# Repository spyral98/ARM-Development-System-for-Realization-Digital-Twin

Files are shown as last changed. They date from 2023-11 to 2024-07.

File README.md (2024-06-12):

# ARM-Development-System-to-Support-Digital-Twin-of-Stepper-Motor 
This repository consists of the work conducted for the thesis "ARM Development System to Support Digital Twin of Stepper Motor". It contains all the files necessary for the development of a fully functional system built around an STM32 Cortex-M4 microcontroller, as well as the code for a demo application for it. It also contains the code for a data representation application using Matlab.



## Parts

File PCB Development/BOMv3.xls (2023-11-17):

SHOPPING BASKET
This is not an invoice
13-Aug-21 08:47:59
 | Mouser No | Mfr. No | Manufacturer | Customer No | Description | RoHS | Lifecycle | Order Qty. | Price (EUR) | Ext.: (EUR)
1 | 696-SMLLXT0805SIUGUB | SML-LXT0805SIUGUBW | Lumex |  | Standard LEDs - SMD SMT 1.25mm X 2.00mm 632nmR,468nmG,468nmB | RoHS Compliant |  | 1 | 0,635 € | 0,64 €
2 | 815-ABM8-16.0-10-1UT | ABM8-16.000MHZ-10-1-U-T | ABRACON |  | Crystals CRYSTAL 16.0000MHZ 10PF SMD | RoHS Compliant |  | 1 | 0,822 € | 0,82 €
3 | 652-SF-0603HIA350M-2 | SF-0603HIA350M-2 | Bourns |  | Surface Mount Fuses 0603 high-inrush multilayer 3.5A Auto | RoHS Compliant | New Product | 1 | 0,94 € | 0,94 €
4 | 511-STM32L4S9ZIT6 | STM32L4S9ZIT6 | STMicroelectronics |  | ARM Microcontrollers - MCU 16/32-BITS MICROS | RoHS Compliant |  | 1 | 19,63 € | 19,63 €
5 | 652-SF-0603HIA100M-2 | SF-0603HIA100M-2 | Bourns |  | Surface Mount Fuses 1 AMP .24 OHM 32VDC | RoHS Compliant | New Product | 1 | 0,94 € | 0,94 €
6 | 755-RSX101MM-30TFTR | RSX101MM-30TFTR | ROHM Semiconductor |  | Schottky Diodes & Rectifiers 30V VR 1A 0.39V VF PMDU; SOD-123FL | RoHS Compliant By Exemption |  | 2 | 0,457 € | 0,91 €
7 | 748-CM1231-02SO | CM1231-02SO | ON Semiconductor |  | ESD Suppressors / TVS Diodes 2-ch. EP series dual | RoHS Compliant |  | 1 | 0,584 € | 0,58 €
8 | 604-AP2012MGC | AP2012MGC | Kingbright |  | Standard LEDs - SMD GRN WATER CLEAR 0805 | RoHS Compliant |  | 1 | 0,50 € | 0,50 €
9 | 113-DTSZML62KVTR | DTSZML-62K-V-T/R | Diptronics |  | Tactile Switches SMT Type (Pitch4.5mm) | RoHS Compliant |  | 1 | 0,381 € | 0,38 €
10 | 688-SSSS811101 | SSSS811101 | Alps Alpine |  | Slide Switches SPDT HORZ GRND 1.5mm | RoHS Compliant |  | 1 | 1,04 € | 1,04 €
11 | 595-TL1963A-33KTTR | TL1963A-33KTTR | Texas Instruments |  | LDO Voltage Regulators 1.5A Lo-Noise Fast- Trans-Resp LDO Reg | RoHS Compliant |  | 1 | 2,88 € | 2,88 €
12 | 963-FBTH1608HE101-T | FBTH1608HE101-T | Taiyo Yuden |  | Ferrite Beads 0603 100ohm 25% AEC-Q200 | RoHS Compliant |  | 2 | 0,254 € | 0,51 €
13 | 80-C0805C106K3P | C0805C106K3PACTU | KEMET |  | Multilayer Ceramic Capacitors MLCC - SMD/SMT 25V 10uF X5R 0805 10% | RoHS Compliant |  | 2 | 0,288 € | 0,58 €
14 | 80-C0603C104J4RAC | C0603C104J4RAC | KEMET |  | Multilayer Ceramic Capacitors MLCC - SMD/SMT 16V 0.1uF X7R 0603 5% | RoHS Compliant |  | 17 | 0,034 € | 0,58 €
15 | 71-CRCW0603330RJNEB | CRCW0603330RJNEB | Vishay |  | Thick Film Resistors - SMD 1/10watt 330ohms 5% | RoHS Compliant By Exemption |  | 1 | 0,085 € | 0,09 €
16 | 71-RCG060310K0JNEA | RCG060310K0JNEA | Vishay |  | Thick Film Resistors - SMD .1watt 10kohms 5% 0603 200ppm | RoHS Compliant |  | 4 | 0,085 € | 0,34 €
17 | 71-CRCW080522R0JNEAH | CRCW080522R0JNEAHP | Vishay |  | Thick Film Resistors - SMD 1/2watt 22ohms 5% High Power AEC-Q200 | RoHS Compliant By Exemption |  | 30 | 0,171 € | 5,13 €
18 | 71-CRCW060347R0FKEAC | CRCW060347R0FKEAC | Vishay |  | Thick Film Resistors - SMD 1/10Watt 47ohms 1% Commercial Use | RoHS Compliant By Exemption |  | 1 | 0,085 € | 0,09 €
19 | 71-CRCW06032R00FKEAC | CRCW06032R00FKEAC | Vishay |  | Thick Film Resistors - SMD 1/10Watt 2ohms 1% Commercial Use | RoHS Compliant By Exemption |  | 1 | 0,136 € | 0,14 €
20 | 71-CRCW06034K70JNEAC | CRCW06034K70JNEAC | Vishay |  | Thick Film Resistors - SMD 1/10Watt 4.7Kohms 5% Commercial Use | RoHS Compliant By Exemption |  | 10 | 0,027 € | 0,27 €
21 | 80-C0805C105K4R | C0805C105K4RACTU | KEMET |  | Multilayer Ceramic Capacitors MLCC - SMD/SMT 16V 1uF X7R 0805 10% | RoHS Compliant |  | 3 | 0,119 € | 0,36 €
22 | 649-10118194-0001LF | 10118194-0001LF | FCI / Amphenol |  | USB Connectors 5P MICRO USB TYPE B RCPT W/ REAR PEGS | RoHS Compliant |  | 1 | 0,364 € | 0,36 €
23 | 621-DMPH4015SSS-13 | DMPH4015SSS-13 | Diodes Incorporated |  | MOSFET MOSFET BVDSS: 31V-40V |  |  | 1 | 1,13 € | 1,13 €
24 | 538-90136-2106 | 90136-2106 | Molex |  | Headers & Wire Housings 2.54MM CGRIDIII HDR 6P R/A SR SHRD TIN | RoHS Compliant |  | 4 | 1,23 € | 4,92 €
25 | 538-90136-2107 | 90136-2107 | Molex |  | Headers & Wire Housings 2.54MM CGRIDIII HDR 7P R/A SR SHRD TIN | RoHS Compliant |  | 2 | 1,39 € | 2,78 €
26 | 538-90136-2103 | 90136-2103 | Molex |  | Headers & Wire Housings 2.54MM CGRIDIII HDR 3P R/A SR SHRD TIN | RoHS Compliant |  | 1 | 1,48 € | 1,48 €
27 | 538-90136-2104 | 90136-2104 | Molex |  | Headers & Wire Housings 2.54MM CGRIDIII HDR 4P R/A SR SHRD TIN | RoHS Compliant |  | 1 | 1,41 € | 1,41 €
28 | 200-2SNBKG | 2SN-BK-G | Samtec |  | Headers & Wire Housings 2.00 mm Shunt | RoHS Compliant |  | 10 | 0,248 € | 2,48 €
29 | 651-1935187 | 1935187 | Phoenix Contact |  | Fixed Terminal Blocks PT 1.5/4-5.0-H | RoHS Compliant By Exemption |  | 1 | 0,78 € | 0,78 €
30 | 80-C0603C100J3HACTU | C0603C100J3HACTU | KEMET |  | Multilayer Ceramic Capacitors MLCC - SMD/SMT 25V 10pF X8R 0603 5% | RoHS Compliant |  | 2 | 0,085 € | 0,17 €
31 | 80-C0805C475K9P | C0805C475K9PACTU | KEMET |  | Multilayer Ceramic Capacitors MLCC - SMD/SMT 6.3V 4.7uF X5R 0805 10% | RoHS Compliant |  | 2 | 0,186 € | 0,37 €
32 | 80-C0805C225K4P | C0805C225K4PACTU | KEMET |  | Multilayer Ceramic Capacitors MLCC - SMD/SMT 16V 2.2uF X5R 0805 10% | RoHS Compliant |  | 1 | 0,237 € | 0,24 €
33 | 80-C0603C103J5R | C0603C103J5RACTU | KEMET |  | Multilayer Ceramic Capacitors MLCC - SMD/SMT 50V 0.01uF X7R 0603 5% | RoHS Compliant |  | 1 | 0,085 € | 0,09 €
34 | 71-CRCW06031K00JNEAC | CRCW06031K00JNEAC | Vishay |  | Thick Film Resistors - SMD 1/10Watt 1Kohms 5% Commercial Use | RoHS Compliant By Exemption |  | 10 | 0,025 € | 0,25 €
35 | 71-CRCW08050000Z0EAC | CRCW08050000Z0EAC | Vishay |  | Thick Film Resistors - SMD 1/8Watt 0ohms Commercial Use | RoHS Compliant By Exemption |  | 3 | 0,085 € | 0,26 €
36 | 200-SSQ10801FS | SSQ-108-01-F-S | Samtec |  | Headers & Wire Housings Tiger Buy Socket Strip with Square Tails, 0.100 Pitch | RoHS Compliant |  | 2 | 1,37 € | 2,74 €
37 | 200-SSQ10201TS | SSQ-102-01-T-S | Samtec |  | Headers & Wire Housings Tiger Buy Socket Strip with Square Tails, 0.100 Pitch | RoHS Compliant |  | 1 | 0,263 € | 0,26 €
38 | 200-SSQ10101TS | SSQ-101-01-T-S | Samtec |  | Headers & Wire Housings Tiger Buy Socket Strip with Square Tails, 0.100 Pitch | RoHS Compliant |  | 1 | 0,466 € | 0,47 €
39 | 200-SSQ10401LD | SSQ-104-01-L-D | Samtec |  | Headers & Wire Housings Tiger Buy Socket Strip with Square Tails, 0.100 Pitch | RoHS Compliant |  | 1 | 1,49 € | 1,49 €
40 | 200-TSW20207FS | TSW-202-07-F-S | Samtec |  | Headers & Wire Housings Classic PCB Header Strips, 0.100 pitch | RoHS Compliant |  | 2 | 0,373 € | 0,75 €
41 | 200-TMM10303FS | TMM-103-03-F-S | Samtec |  | Headers & Wire Housings Low Profile Tiger Eye Header Strips, 2.00 mm Pitch | RoHS Compliant |  | 8 | 0,491 € | 3,93 €
By submitting your order you agree to these terms and conditions. (https://eu.mouser.com/saleterms) |  |  |  |  |  |  |  |  | Merchandise: | 63,71 €
Prices are reflected at the date and time shown. |  |  |  |  |  |  |  |  | Delivery Charge: | 0,00 €

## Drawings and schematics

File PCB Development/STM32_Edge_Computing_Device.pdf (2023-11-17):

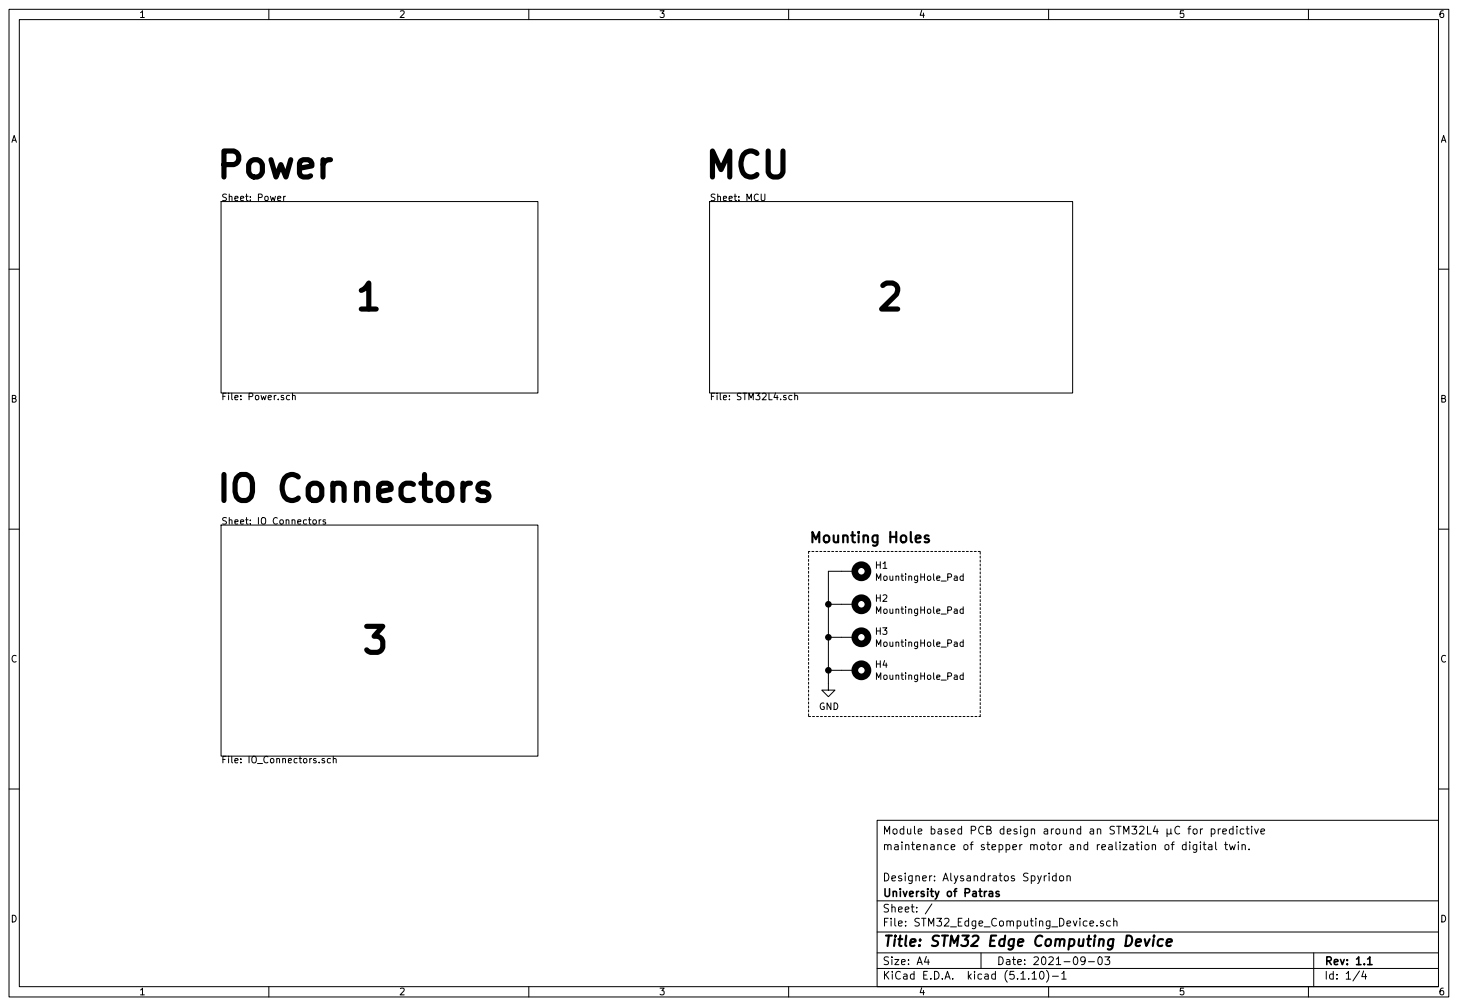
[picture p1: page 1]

Module based PCB design around an STM32L4 C for predictive
maintenance of stepper motor and realization of digital twin.

Designer: Alysandratos Spyridon
File: STM32_Edge_Computing_Device.sch Sheet: / University of Patras

Id: 1/4 Title: STM32 Edge Computing Device

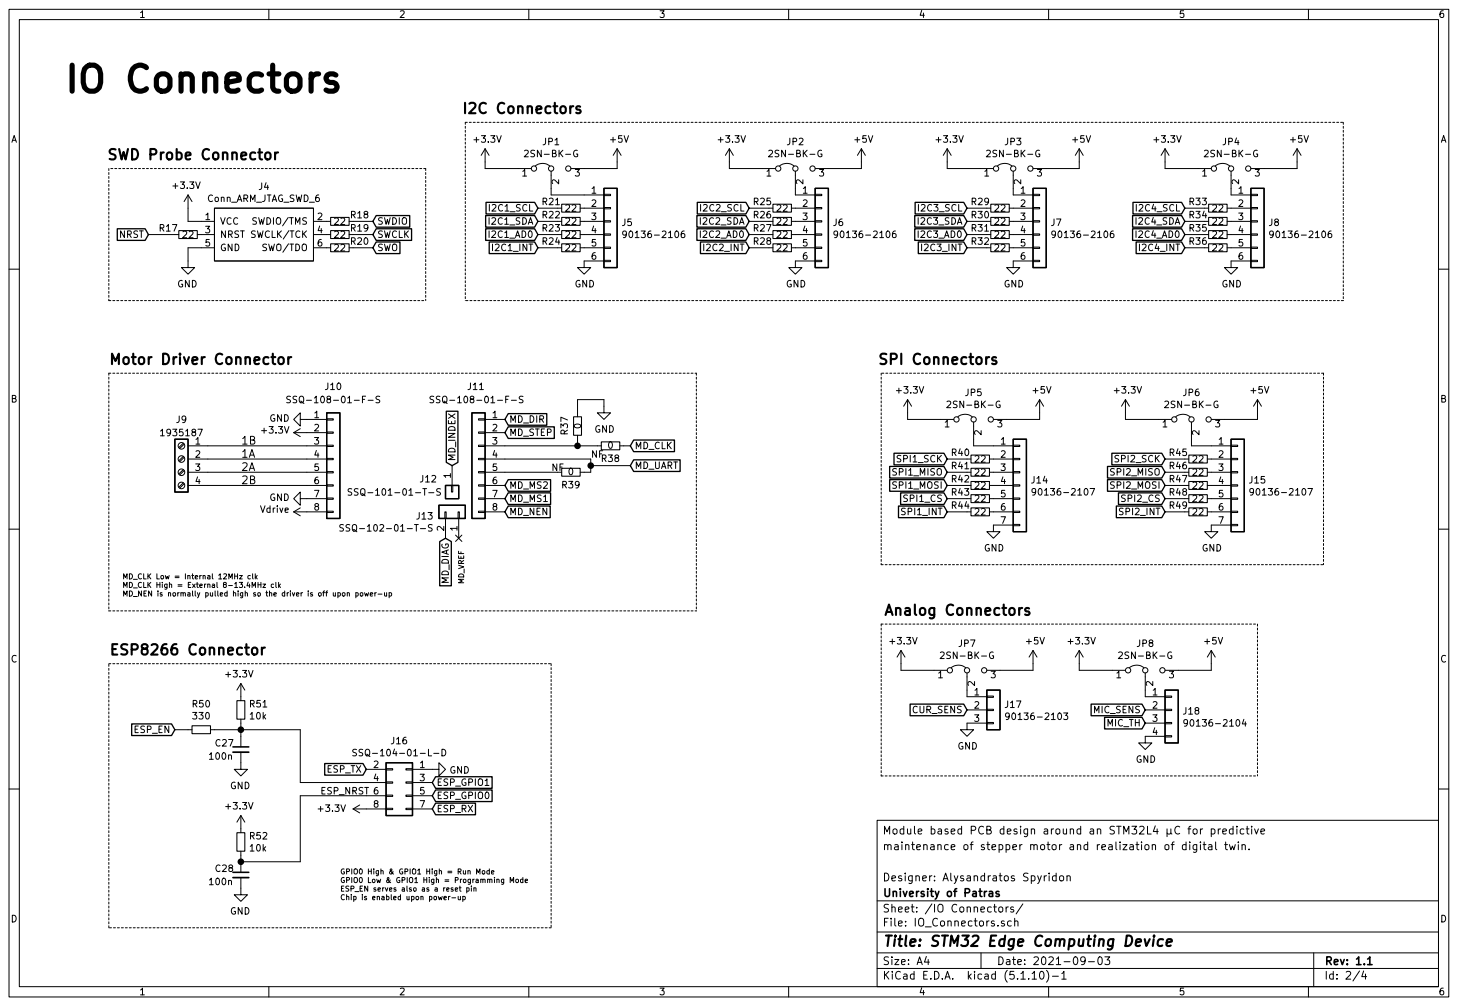
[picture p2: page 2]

MD_CLK Low = Internal 12MHz clk MD_CLK High = External 8-13.4MHz clk MD_NEN is normally pulled high so the driver is off upon power-up Motor Driver Connector

Module based PCB design around an STM32L4 C for predictive R50

maintenance of stepper motor and realization of digital twin.

GPIO0 High & GPIO1 High = Run Mode GPIO0 Low & GPIO1 High = Programming Mode ESP_EN serves also as a reset pin Chip is enabled upon power-up

Designer: Alysandratos Spyridon
File: IO_Connectors.sch Sheet: /IO Connectors/ University of Patras

Id: 2/4 Title: STM32 Edge Computing Device

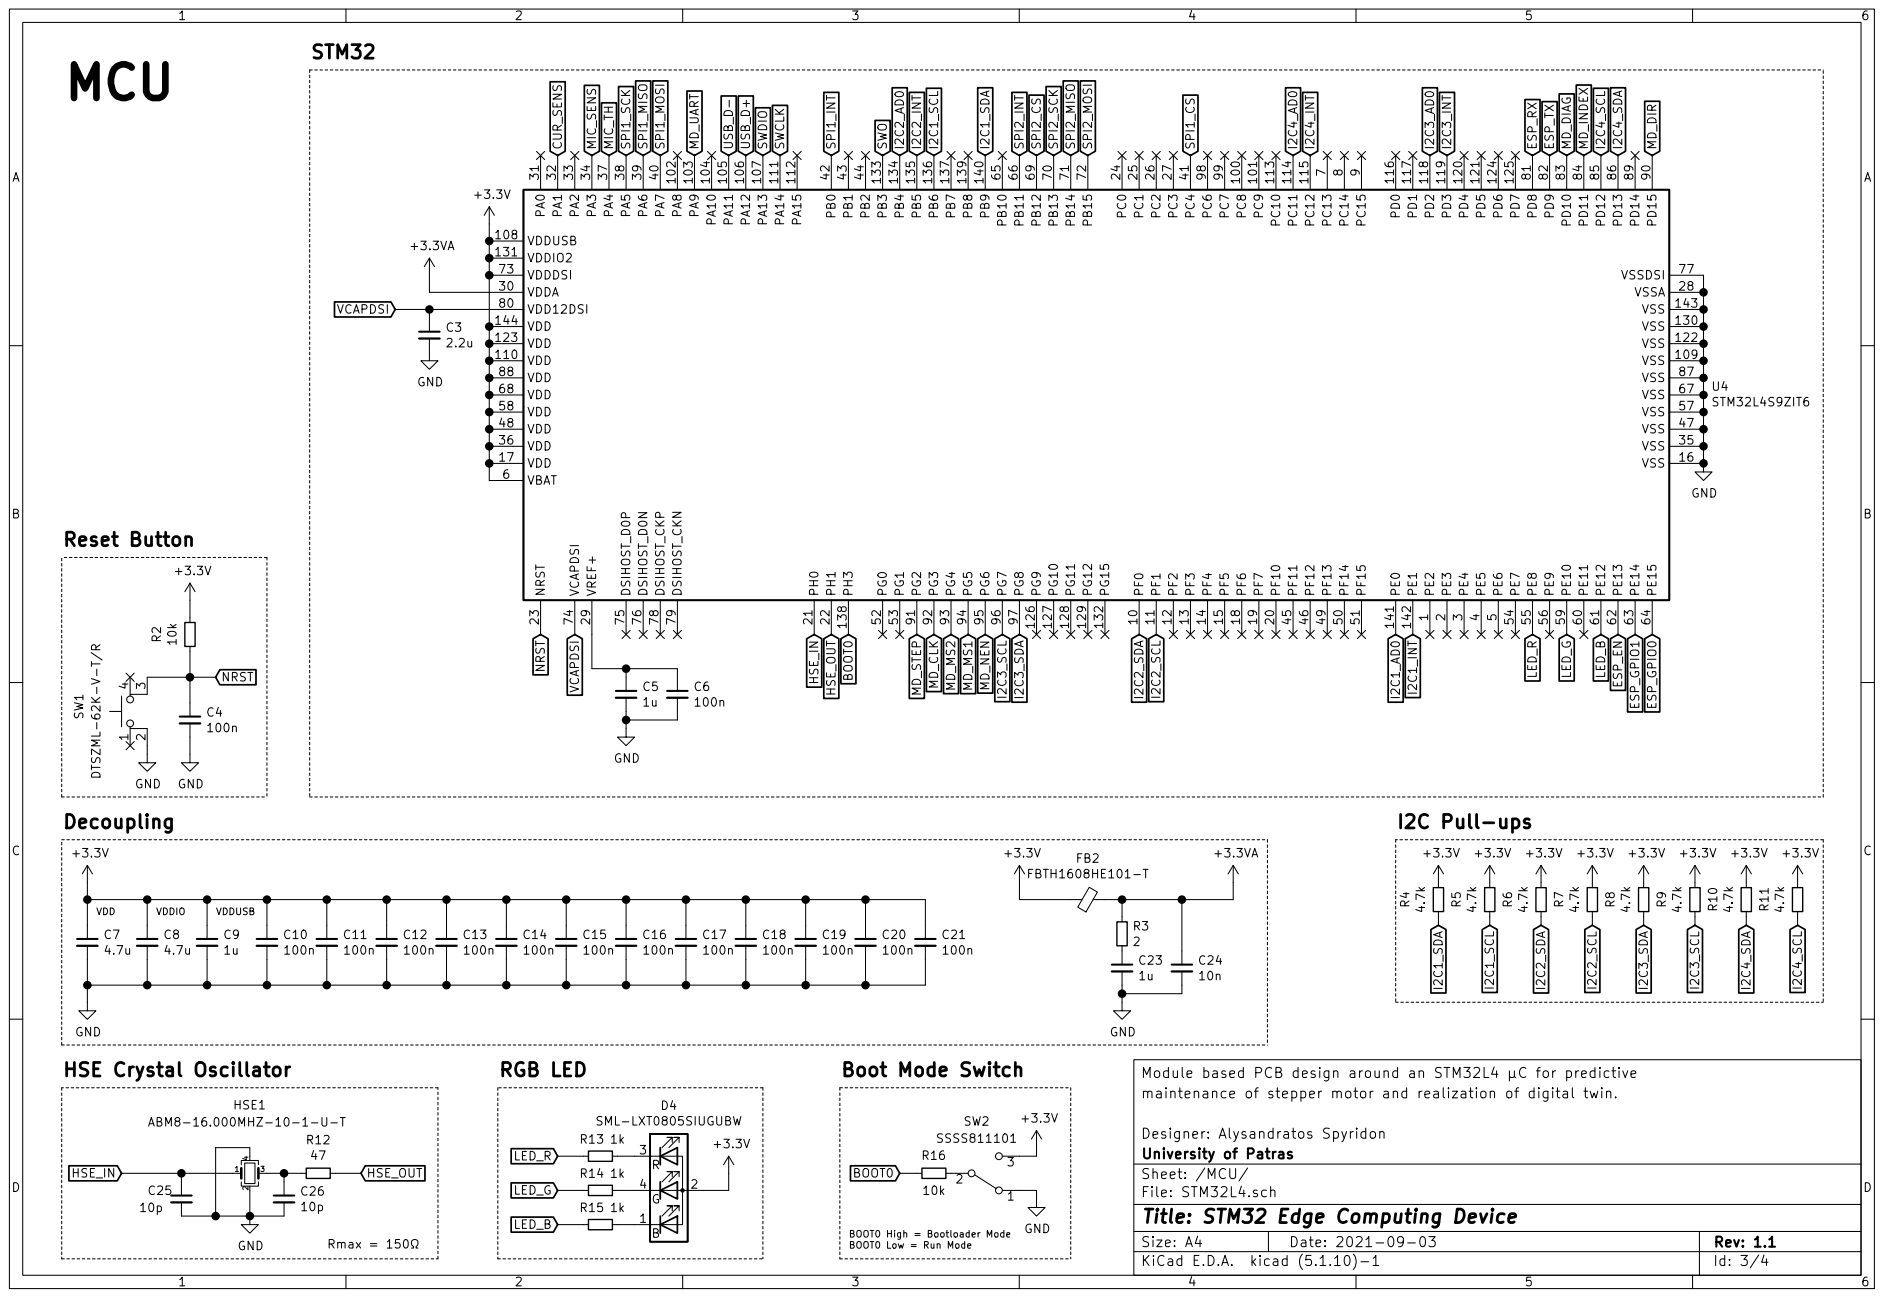
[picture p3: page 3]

5 PE7 54 PE8 55 PE9 56 PF0 10 PF1 11 PF10 20 PF11 45 PF12 46 PF13 49 PF14 50 PF15 51 PF2 12 PF3 13 PF4 14 PF5 15 PF6 18 PF7 19 PG0 52 PG1 53 PG10 127 PG11 128 PG12 129 PG15 132 PG2 91 PG3 92 PG4 93 PG5 94 PG6 95 PG7 96 PG8 97 PG9 126 PH0 21 PH1 22 PH3 138 VBAT 6 VCAPDSI 74 VDD 110 VDD 123 VDD 144 VDD 17 VDD 36 VDD 48 VDD 58 VDD 68 VDD 88 VDD12DSI 80 VDDA 30 VDDDSI 73 VDDIO2 131 VDDUSB 108 VREF+ 29

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

Designer: Alysandratos Spyridon
File: STM32L4.sch Sheet: /MCU/ University of Patras

Id: 3/4 Title: STM32 Edge Computing Device

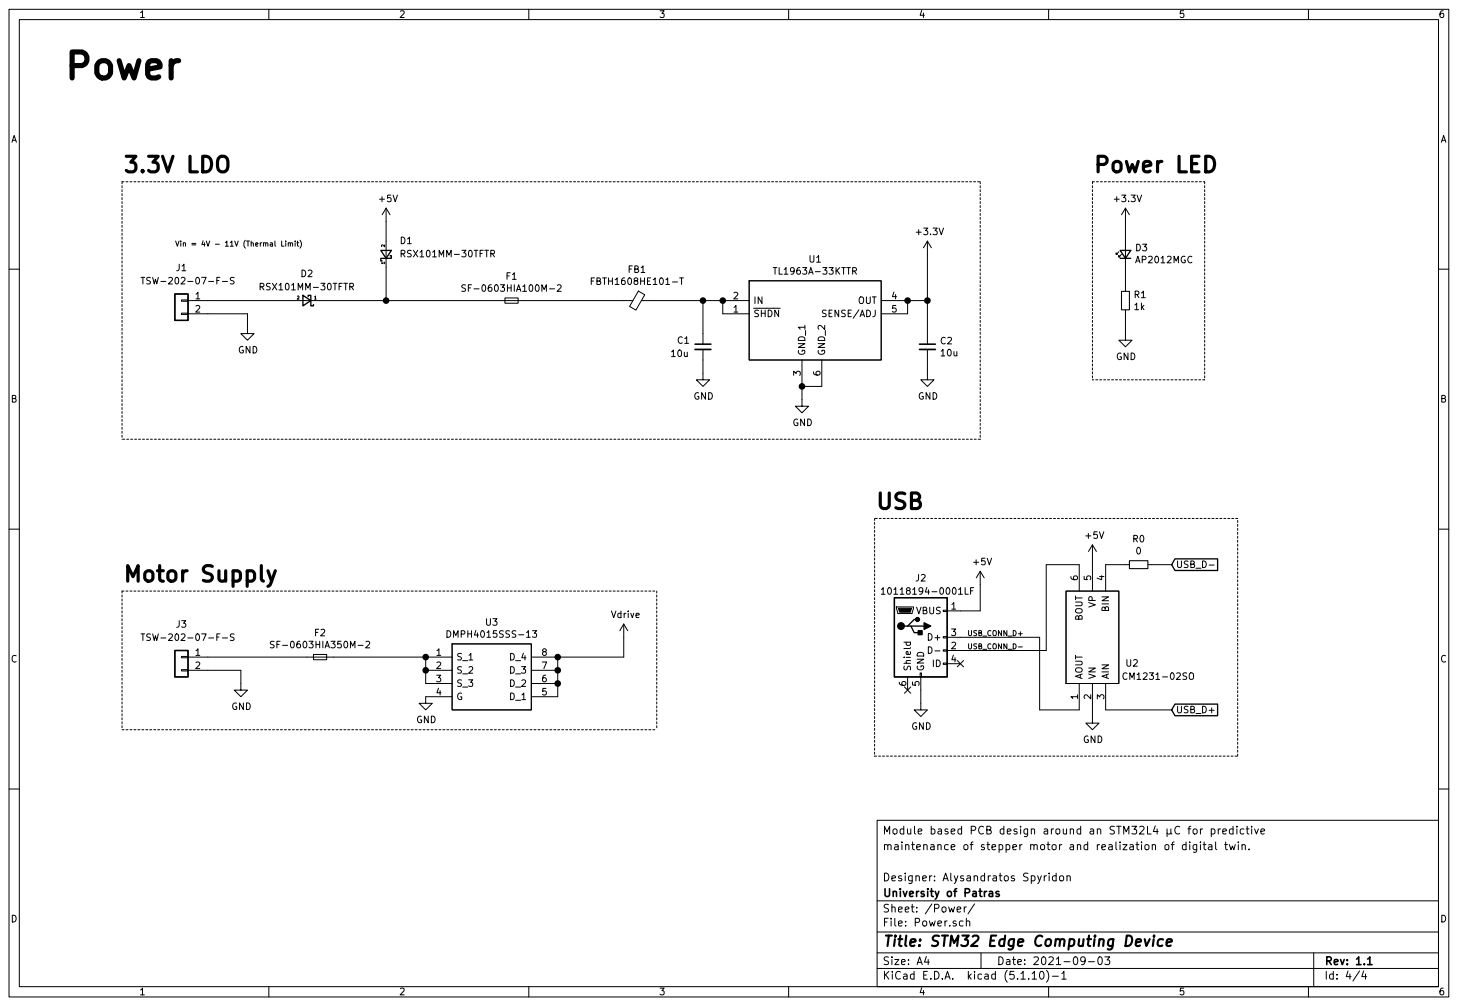
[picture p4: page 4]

Vin = 4V - 11V (Thermal Limit) 3.3V LDO

maintenance of stepper motor and realization of digital twin.

Designer: Alysandratos Spyridon
File: Power.sch Sheet: /Power/ University of Patras

Id: 4/4 Title: STM32 Edge Computing Device

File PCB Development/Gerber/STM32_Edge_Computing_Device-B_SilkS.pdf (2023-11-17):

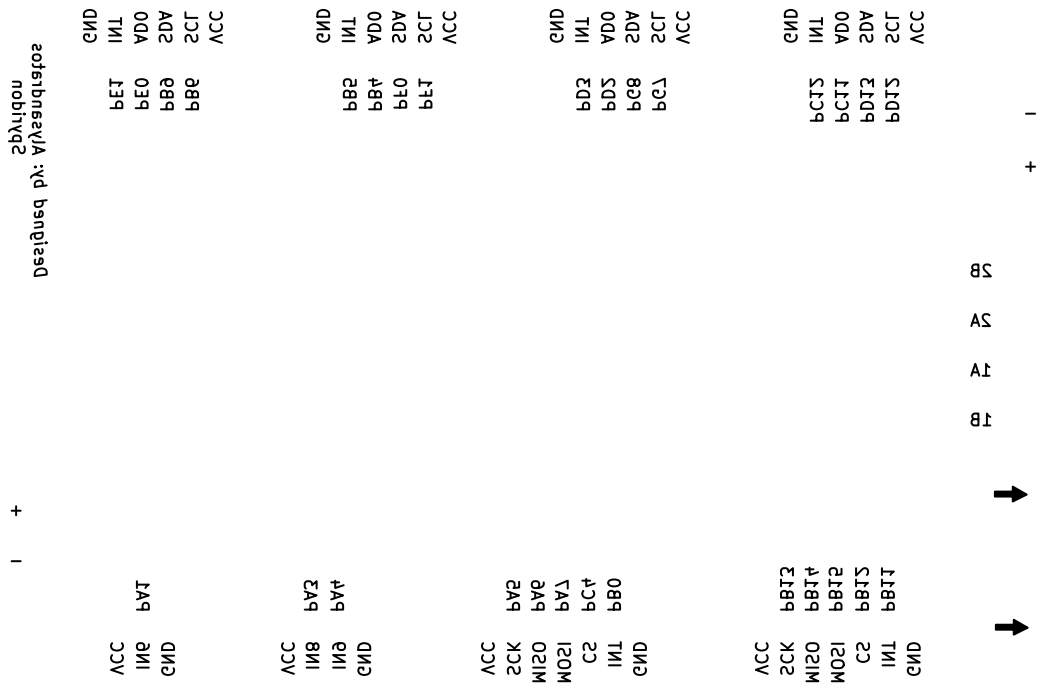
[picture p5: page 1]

1B -+ -+ PE1 PE0 PB9 PB6 PB5 PB4 PF0 PF1 PD3 PD2 PG8 PG7 PC12 PC11 PD13 PD12 GND INT AD0 SDA SCL VCC GND INT AD0 SDA SCL VCC GND INT AD0 SDA SCL VCC GND INT AD0 SDA SCL VCC PA1 PA3 PA4 PA5 PA6 PA7 PC4 PB0 PB13 PB14 PB15 PB12 PB11 IN8 IN9 GND VCC GND IN6 VCC VCCCS MOSI SCK GND INT MISO GNDCS INT MISO MOSI VCC SCK

Spyridon Alysandratos Designed by: 2B

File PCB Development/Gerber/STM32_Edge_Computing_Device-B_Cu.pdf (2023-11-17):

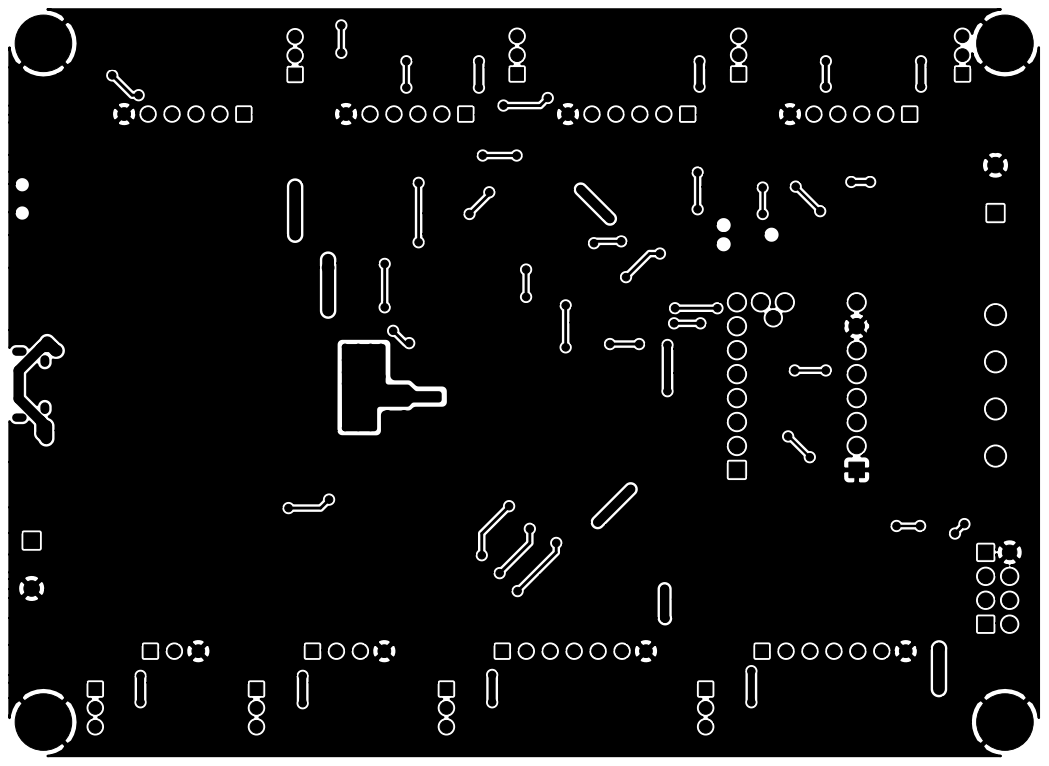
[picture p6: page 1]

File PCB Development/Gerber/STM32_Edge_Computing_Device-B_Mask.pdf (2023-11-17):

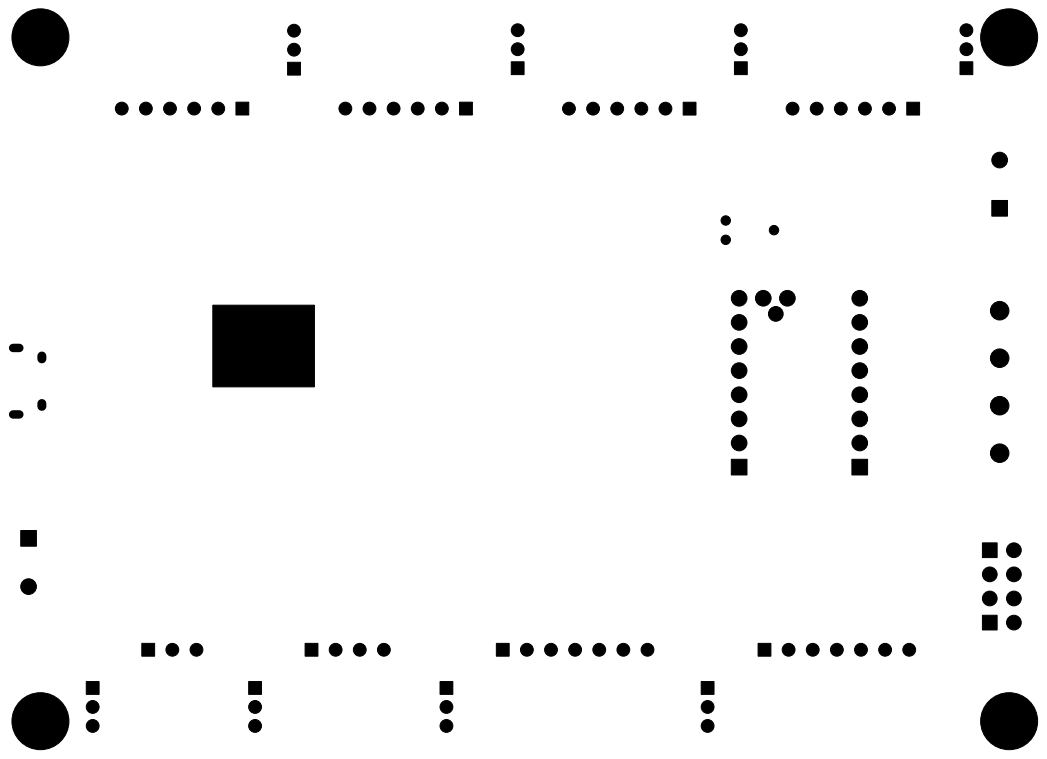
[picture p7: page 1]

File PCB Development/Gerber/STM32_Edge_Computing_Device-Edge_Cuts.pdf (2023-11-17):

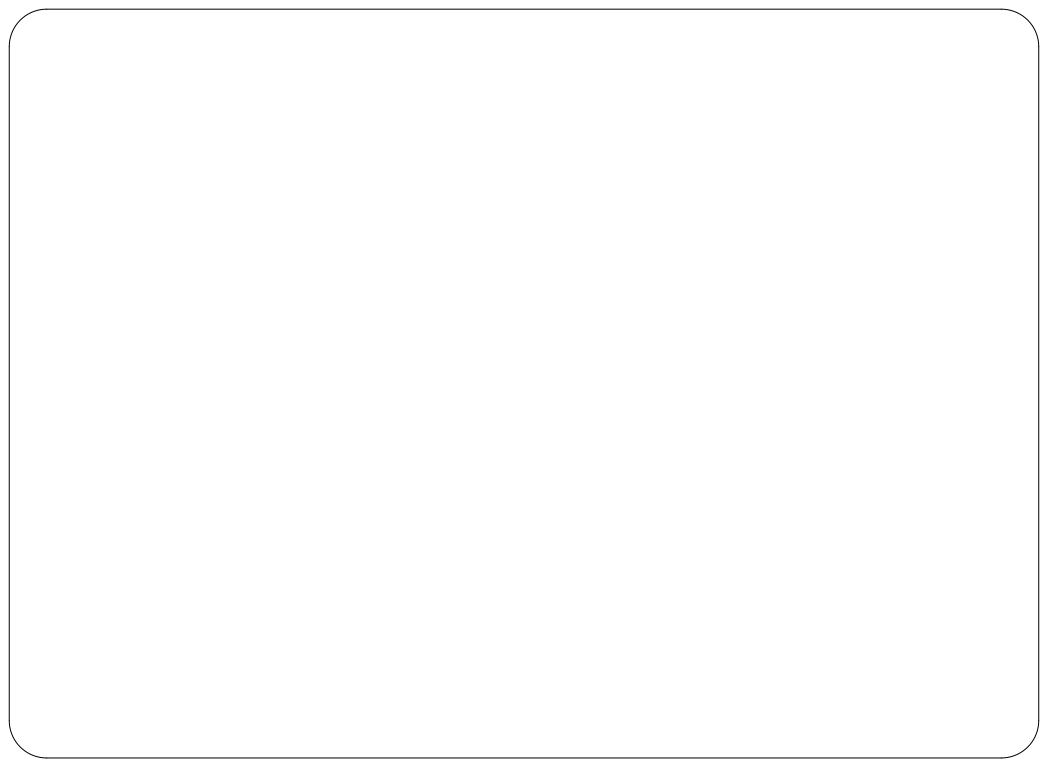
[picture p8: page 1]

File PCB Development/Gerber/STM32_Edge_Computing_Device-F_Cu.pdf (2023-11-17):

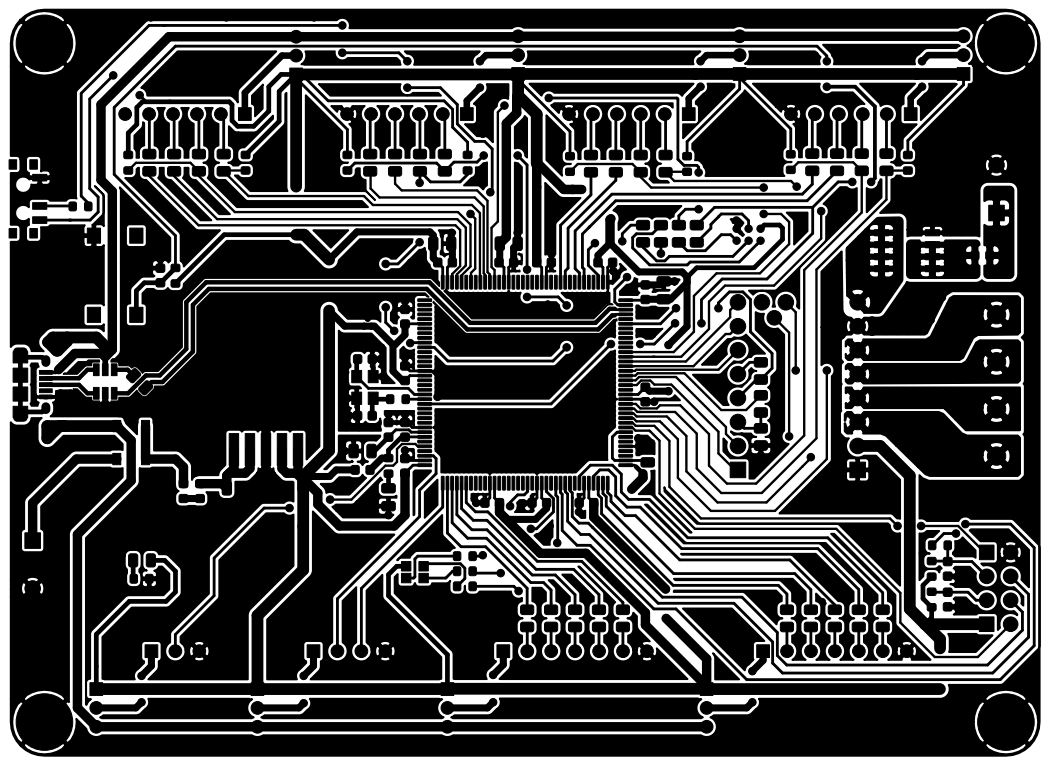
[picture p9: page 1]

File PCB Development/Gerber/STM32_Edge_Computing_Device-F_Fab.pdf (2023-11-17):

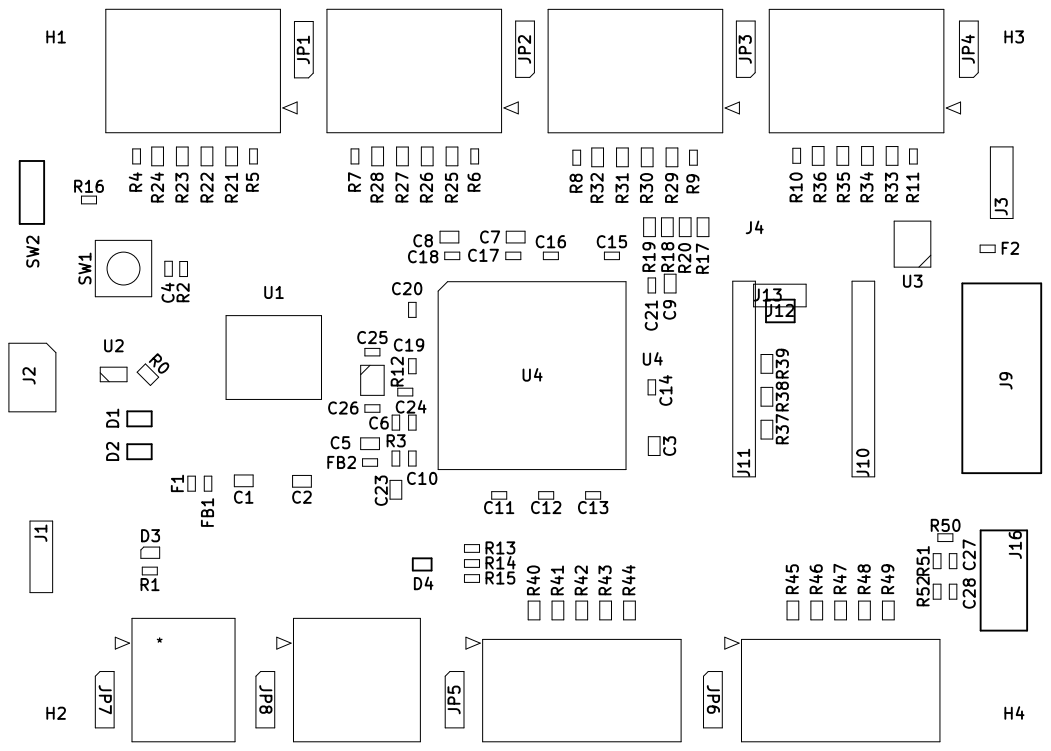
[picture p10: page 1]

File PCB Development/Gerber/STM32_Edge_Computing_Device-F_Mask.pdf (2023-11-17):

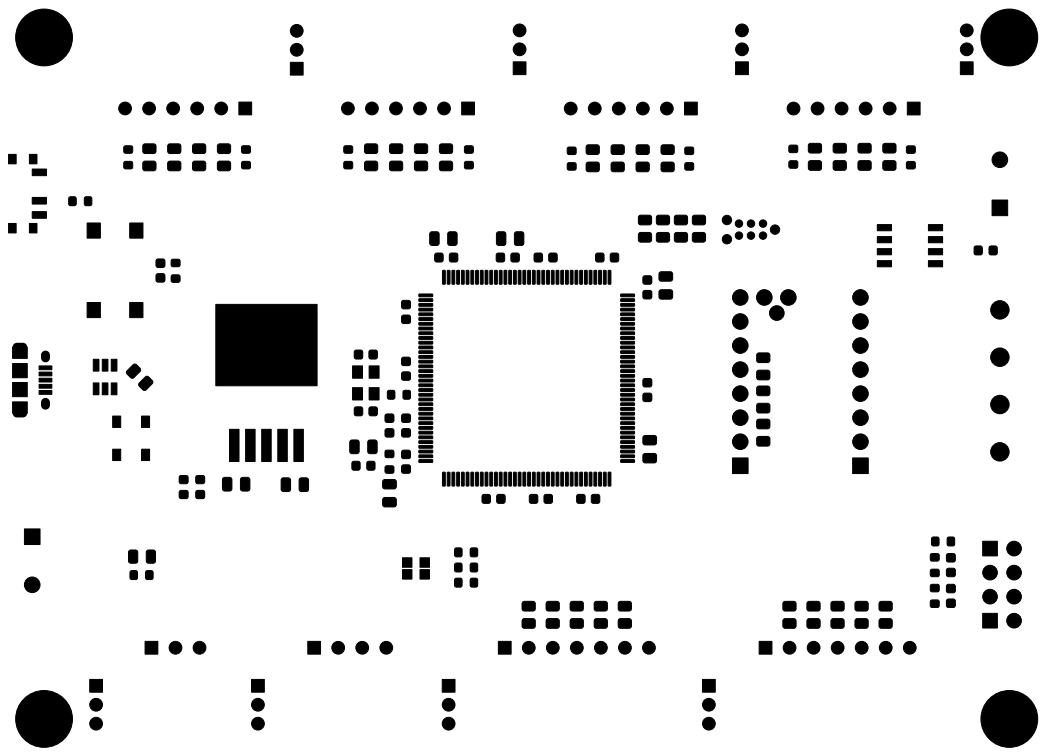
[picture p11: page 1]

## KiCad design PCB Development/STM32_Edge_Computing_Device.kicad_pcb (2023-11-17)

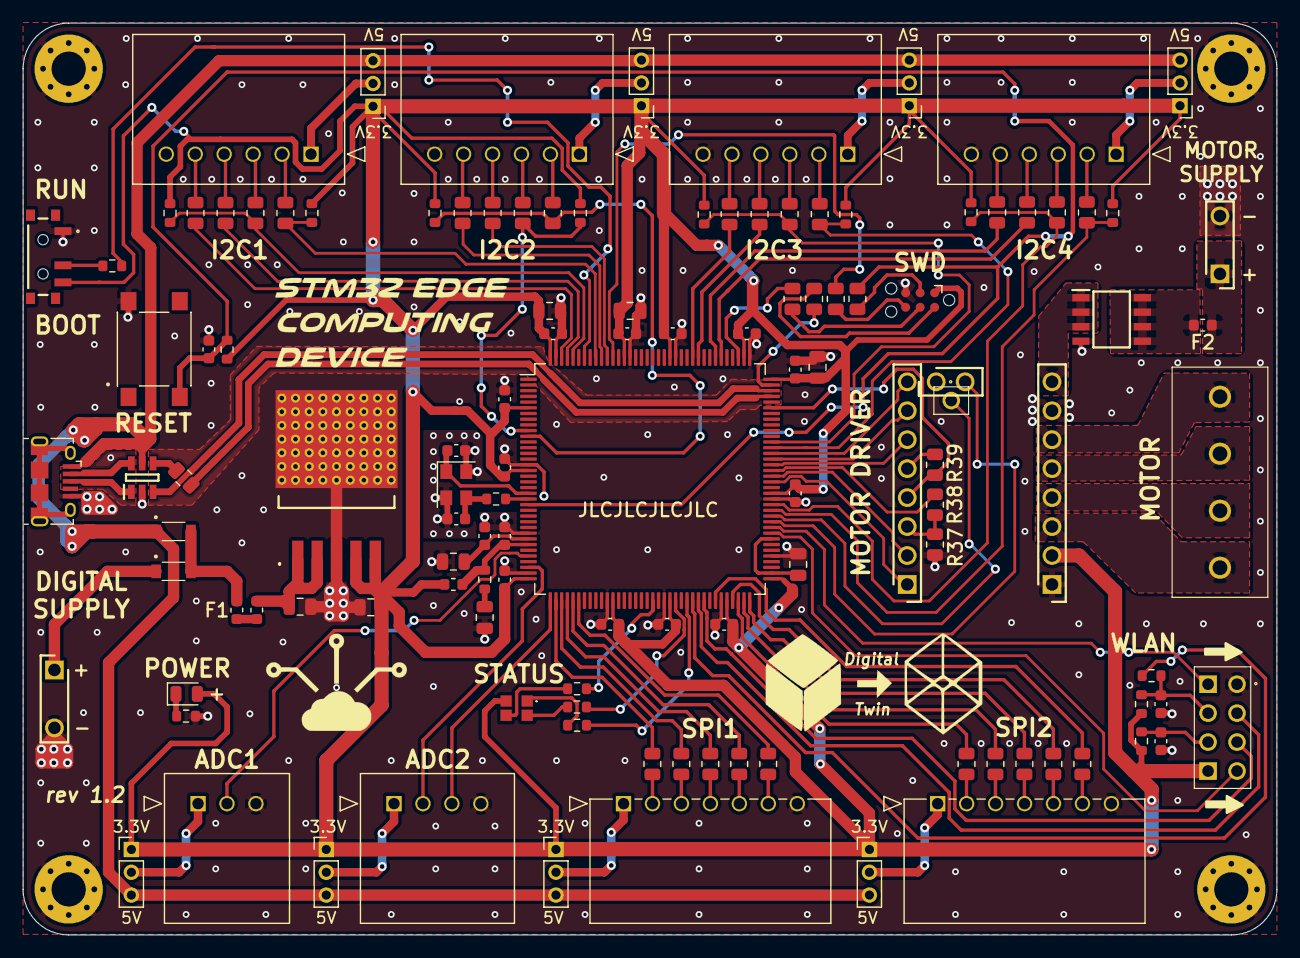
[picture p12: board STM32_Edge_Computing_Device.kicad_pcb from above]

Board: 2 copper layers, 110.0 x 80.0 mm, 125 parts (0 on the bottom side), 124 nets.

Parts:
C1, C2: 10u; C_0805_2012Metric
C3: 2.2u; C_0805_2012Metric
C4, C6, C10, C11, C12, C13, C14, C15, C16, C17, C18, C19, C20, C21, C27, C28: 100n; C_0603_1608Metric
C5, C9, C23: 1u; C_0805_2012Metric
C7, C8: 4.7u; C_0805_2012Metric
C24: 10n; C_0603_1608Metric
C25, C26: 15p; C_0603_1608Metric
D1, D2: RSX101MM-30TFTR; RSX101MM30TFTR
D3: AP2012MGC; LED_0805_2012Metric
D4: SML-LXT0805SIUGUBW; SMLLXT0805SIUGUBW
F1: SF-0603HIA100M-2; Fuse_0603_1608Metric
F2: SF-0603HIA300M-2; Fuse_0603_1608Metric
FB1, FB2: FBTH1608HE101-T; L_0603_1608Metric
H1, H2, H3, H4: MountingHole_Pad; MountingHole_3mm_Pad_Via
J1, J3: TSW-202-07-F-S; HDRV2W64P254X508_1X2_762X241X838P
J2: 10118194-0001LF; USB_Micro-B_Amphenol_10118194_Horizontal
J4: Conn_ARM_JTAG_SWD_6; Tag-Connect_TC2030-IDC-NL_2x03_P1.27mm_Vertical
J5, J6, J7, J8: 90136-2106; 901362106
J9: 1935187
J10, J11: SSQ-108-01-F-S; RHDR8W64P254_1X8_2083X241X851P
J12: SSQ-101-01-T-S; SSQ-101-XX-YYY-S
J13: SSQ-102-01-T-S; RHDR2W64P254_1X2_559X241X851P
J14, J15: 90136-2107; 901362107
J16: SSQ-104-01-L-D; SSQ-104-XX-YYY-D
J17: 90136-2103; 901362103
J18: 90136-2104; 901362104
JP1, JP2, JP3, JP4, JP5, JP6, JP7, JP8: 2SN-BK-G; PinHeader_1x03_P2.00mm_Vertical
R0, R37, R38, R39: 0; R_0805_2012Metric
R1, R13, R14, R15: 1k; R_0603_1608Metric
R2, R16, R51, R52: 10k; R_0603_1608Metric
R3: 2; R_0603_1608Metric
R4, R5, R6, R7, R8, R9, R10, R11: 4.7k; R_0603_1608Metric
R12: 910; R_0603_1608Metric
R17, R18, R19, R20, R21, R22, R23, R24, R25, R26, R27, R28, R29, R30, R31, R32, R33, R34, R35, R36, R40, R41, R42, R43, R44, R45, R46, R47, R48, R49: 22; R_0805_2012Metric
R50: 330; R_0603_1608Metric
SW1: DTSZML-62K-V-T/R; SW_Push_1P1T_NO_6x6mm_H4.5mm
SW2: SSSS811101
U1: TL1963A-33KTTR; TL1963A33KTTR
U2: CM1231-02SO; SOT95P280X145-6N
U3: DMPH4015SSS-13; SOIC127P600X170-8N
U4: STM32L4S9ZIT6; LQFP-144_20x20mm_P0.5mm
XTAL1: 7M-12.000MEHE-T; Crystal_SMD_3225-4Pin_3.2x2.5mm_custom

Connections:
+3.3VA: C24.1, FB2.2, R3.1, U4.30
+3V3: C2.1, C7.1, C8.1, C9.1, C10.1, C11.1, C12.1, C13.1, C14.1, C15.1, C16.1, C17.1, C18.1, C19.1, C20.1, C21.1, D3.2, D4.2, FB2.1, J4.1, J10.2, J16.8, JP1.1, JP2.1, JP3.1, JP4.1, JP5.1, JP6.1, JP7.1, JP8.1, R2.1, R4.1, R5.1, R6.1, R7.1, R8.1, R9.1, R10.1, R11.1, R51.1, R52.1, SW2.3, U1.4, U1.5, U4.6, U4.17, U4.36, U4.48, U4.58, U4.68, U4.73, U4.88, U4.108, U4.110, U4.123, U4.131, U4.144
+5V: D1.2, J2.1, JP1.3, JP2.3, JP3.3, JP4.3, JP5.3, JP6.3, JP7.3, JP8.3, U2.5
/IO Connectors/1A: J9.2, J10.4
/IO Connectors/1B: J9.1, J10.3
/IO Connectors/2A: J9.3, J10.5
/IO Connectors/2B: J9.4, J10.6
/Power/USB_CONN_D+: J2.3, U2.1
/Power/USB_CONN_D-: J2.2, U2.6
BOOT0: R16.1, U4.138
CUR_SENS: J17.2, U4.32
ESP_EN: R50.2, U4.62
ESP_GPIO0: J16.5, U4.64
ESP_GPIO2: J16.3, U4.63
ESP_RX: J16.7, U4.81
ESP_TX: J16.2, U4.82
GND: C1.2, C2.2, C3.2, C4.2, C5.2, C6.2, C7.2, C8.2, C9.2, C10.2, C11.2, C12.2, C13.2, C14.2, C15.2, C16.2, C17.2, C18.2, C19.2, C20.2, C21.2, C23.2, C24.2, C25.2, C26.2, C27.2, C28.2, H1.1, H2.1, H3.1, H4.1, J1.2, J2.5, J3.2, J4.5, J5.6, J6.6, J7.6, J8.6, J10.1, J10.7, J14.7, J15.7, J16.1, J17.3, J18.4, R1.2, R37.1, SW1.2, SW2.1, U1.3, U1.6, U2.2, U3.4, U4.16, U4.28, U4.35, U4.47, U4.57, U4.67, U4.77, U4.87, U4.109, U4.122, U4.130, U4.143, XTAL1.2, XTAL1.4
HSE_IN: C25.1, U4.21, XTAL1.1
HSE_OUT: R12.1, U4.22
I2C1_AD0: R23.2, U4.141
I2C1_INT: R24.2, U4.142
I2C1_SCL: R5.2, R21.2, U4.136
I2C1_SDA: R4.2, R22.2, U4.140
I2C2_AD0: R27.2, U4.134
I2C2_INT: R28.2, U4.135
I2C2_SCL: R7.2, R25.2, U4.11
I2C2_SDA: R6.2, R26.2, U4.10
I2C3_AD0: R31.2, U4.118
I2C3_INT: R32.2, U4.119
I2C3_SCL: R9.2, R29.2, U4.96
I2C3_SDA: R8.2, R30.2, U4.97
I2C4_AD0: R35.2, U4.114
I2C4_INT: R36.2, U4.115
I2C4_SCL: R11.2, R33.2, U4.85
I2C4_SDA: R10.2, R34.2, U4.86
LED_B: R15.2, U4.61
LED_G: R14.2, U4.59
LED_R: R13.2, U4.55
MD_CLK: R38.2, U4.92
MD_DIAG: J13.2, U4.83
MD_DIR: J11.1, U4.90
MD_INDEX: J12.1, U4.84
MD_MS1: J11.7, U4.94
MD_MS2: J11.6, U4.93
MD_NEN: J11.8, U4.95
MD_STEP: J11.2, U4.91
MD_UART: J11.4, R39.2, U4.103
MIC_SENS: J18.2, U4.34
MIC_TH: J18.3, U4.37
NRST: C4.1, R2.2, R17.2, SW1.3, U4.23
unnamed: C1.1, FB1.1, U1.1, U1.2
unnamed: C5.1, C6.1, U4.29
unnamed: C23.1, R3.2
unnamed: C26.1, R12.2, XTAL1.3
unnamed: C27.1, J16.4, R50.1, R51.2
unnamed: C28.1, J16.6, R52.2
unnamed: D1.1, D2.1, F1.1
unnamed: D2.2, J1.1
unnamed: D3.1, R1.1
unnamed: D4.1, R15.1
unnamed: D4.3, R13.1
unnamed: D4.4, R14.1
unnamed: F1.2, FB1.2
unnamed: F2.1, J3.1
unnamed: F2.2, U3.5, U3.6, U3.7, U3.8
unnamed: J4.2, R18.1
unnamed: J4.3, R17.1
unnamed: J4.4, R19.1
unnamed: J4.6, R20.1
unnamed: J5.1, JP1.2
unnamed: J5.2, R21.1
unnamed: J5.3, R22.1
unnamed: J5.4, R23.1
unnamed: J5.5, R24.1
unnamed: J6.1, JP2.2
unnamed: J6.2, R25.1
unnamed: J6.3, R26.1
unnamed: J6.4, R27.1
unnamed: J6.5, R28.1
unnamed: J7.1, JP3.2
unnamed: J7.2, R29.1
unnamed: J7.3, R30.1
unnamed: J7.4, R31.1
unnamed: J7.5, R32.1
unnamed: J8.1, JP4.2
unnamed: J8.2, R33.1
unnamed: J8.3, R34.1
unnamed: J8.4, R35.1
unnamed: J8.5, R36.1
unnamed: J11.3, R37.2, R38.1
unnamed: J11.5, R39.1
unnamed: J14.1, JP5.2
unnamed: J14.2, R40.1
unnamed: J14.3, R41.1
unnamed: J14.4, R42.1
unnamed: J14.5, R43.1
unnamed: J14.6, R44.1
unnamed: J15.1, JP6.2
unnamed: J15.2, R45.1
unnamed: J15.3, R46.1
unnamed: J15.4, R47.1
unnamed: J15.5, R48.1
unnamed: J15.6, R49.1
unnamed: J17.1, JP7.2
unnamed: J18.1, JP8.2
unnamed: R0.2, U2.4
unnamed: R16.2, SW2.2
SPI1_CS: R43.2, U4.41
SPI1_INT: R44.2, U4.42
SPI1_MISO: R41.2, U4.39
SPI1_MOSI: R42.2, U4.40
SPI1_SCK: R40.2, U4.38
SPI2_CS: R48.2, U4.69
SPI2_INT: R49.2, U4.66
SPI2_MISO: R46.2, U4.71
SPI2_MOSI: R47.2, U4.72
SPI2_SCK: R45.2, U4.70
SWCLK: R19.2, U4.111
SWDIO: R18.2, U4.107
SWO: R20.2, U4.133
USB_D+: U2.3, U4.106
USB_D-: R0.1, U4.105
VCAPDSI: C3.1, U4.74, U4.80
Vdrive: J10.8, U3.1, U3.2, U3.3

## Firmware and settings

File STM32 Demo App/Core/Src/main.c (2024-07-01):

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
/* Includes ------------------------------------------------------------------*/
#include "main.h"
#include "cmsis_os.h"
#include "usb_device.h"

/* USER CODE BEGIN Includes */

#include "usb_device.h"
#include "usbd_cdc_if.h"
#include "data_logger.h"
#include "AT_commands.h"
#include "queue.h"
#include "thingspeak.h"
#include "TMP102.h"
#include "BME280.h"
#include "MPU6050.h"
#include "arm_math.h"

/* USER CODE END Includes */

/* USER CODE BEGIN PTD */

#define ADC_BUF_LEN 2048
#define MIC_BUF_LEN 1024
#define CUR_BUF_LEN 1024
#define IMU_BUF_LEN 64
#define FSAMPLING 12000

typedef enum
{
	BUF_EMPTY,
	BUF_HALF_FULL,
	BUF_FULL
} BUF_STATE;

typedef struct
{
	float accel_x[IMU_BUF_LEN];
	float accel_y[IMU_BUF_LEN];
	float accel_z[IMU_BUF_LEN];
	float gyro_x[IMU_BUF_LEN];
	float gyro_y[IMU_BUF_LEN];
	float gyro_z[IMU_BUF_LEN];
} IMU_BUF;


/* USER CODE END PTD */

ADC_HandleTypeDef hadc1;
DMA_HandleTypeDef hdma_adc1;

I2C_HandleTypeDef hi2c1;
I2C_HandleTypeDef hi2c2;
I2C_HandleTypeDef hi2c3;
DMA_HandleTypeDef hdma_i2c1_rx;
DMA_HandleTypeDef hdma_i2c2_rx;
DMA_HandleTypeDef hdma_i2c3_rx;

TIM_HandleTypeDef htim5;
TIM_HandleTypeDef htim6;

UART_HandleTypeDef huart3;
DMA_HandleTypeDef hdma_usart3_tx;
DMA_HandleTypeDef hdma_usart3_rx;

/* Definitions for usb_log_task */
osThreadId_t usb_log_taskHandle;
const osThreadAttr_t usb_log_task_attributes = {
  .name = "usb_log_task",
  .stack_size = 512 * 4,
  .priority = (osPriority_t) osPriorityHigh,
};
/* Definitions for motor_task */
osThreadId_t motor_taskHandle;
const osThreadAttr_t motor_task_attributes = {
  .name = "motor_task",
  .stack_size = 128 * 4,
  .priority = (osPriority_t) osPriorityNormal,
};
/* Definitions for wifi_task */
osThreadId_t wifi_taskHandle;
const osThreadAttr_t wifi_task_attributes = {
  .name = "wifi_task",
  .stack_size = 256 * 4,
  .priority = (osPriority_t) osPriorityBelowNormal,
};
/* Definitions for proc_task */
osThreadId_t proc_taskHandle;
const osThreadAttr_t proc_task_attributes = {
  .name = "proc_task",
  .stack_size = 256 * 4,
  .priority = (osPriority_t) osPriorityAboveNormal,
};
/* Definitions for heartbeat_timer */
osTimerId_t heartbeat_timerHandle;
const osTimerAttr_t heartbeat_timer_attributes = {
  .name = "heartbeat_timer"
};
/* USER CODE BEGIN PV */

uint8_t usb_rx_buffer[USB_RX_BUF_LEN];

uint16_t adc_raw_buf[ADC_BUF_LEN];
float mic_buf[MIC_BUF_LEN];
float cur_buf[CUR_BUF_LEN];

IMU_BUF imu_buf[2], imu_fft_buf;


float fft_mic_in_buf[MIC_BUF_LEN/2];
float fft_cur_in_buf[MIC_BUF_LEN/2];

float mic_fft_buf[MIC_BUF_LEN/2];
float cur_fft_buf[CUR_BUF_LEN/2];


IMU_BUF fft_in_imu;

float test_imu[6*IMU_BUF_LEN];


//QueueHandle_t logging_q;
BUF_STATE adc_buf_state = BUF_EMPTY;
BUF_STATE imu_buf_state = BUF_EMPTY;

/* USER CODE END PV */

void SystemClock_Config(void);
static void MX_GPIO_Init(void);
static void MX_DMA_Init(void);
static void MX_ADC1_Init(void);
static void MX_TIM6_Init(void);
static void MX_USART3_UART_Init(void);
static void MX_I2C1_Init(void);
static void MX_TIM5_Init(void);
static void MX_I2C3_Init(void);
static void MX_I2C2_Init(void);
void usb_log_task_entry(void *argument);
void motor_task_entry(void *argument);
void wifi_task_entry(void *argument);
void proc_task_entry(void *argument);
void heartbeat_timer_callback(void *argument);

/**
  * @brief  The application entry point.
  * @retval int
  */
int main(void)
{
  /* MCU Configuration--------------------------------------------------------*/

  /* Reset of all peripherals, Initializes the Flash interface and the Systick. */
  HAL_Init();

  /* Configure the system clock */
  SystemClock_Config();

  /* Initialize all configured peripherals */
  MX_GPIO_Init();
  MX_DMA_Init();
  MX_ADC1_Init();
  MX_TIM6_Init();
  MX_USART3_UART_Init();
  MX_I2C1_Init();
  MX_TIM5_Init();
  MX_I2C3_Init();
  MX_I2C2_Init();
  /* USER CODE BEGIN 2 */

  TMP102_init(&hi2c1);

  BME280_init(&hi2c3);



  if (HAL_ADCEx_Calibration_Start(&hadc1, ADC_SINGLE_ENDED) != HAL_OK)
  	  Error_Handler();

  if (HAL_ADC_Start_DMA(&hadc1, (uint32_t*) adc_raw_buf, ADC_BUF_LEN) != HAL_OK)
	  Error_Handler();

  if (HAL_TIM_Base_Start(&htim6) != HAL_OK)
	  Error_Handler();

  /* USER CODE END 2 */

  /* Init scheduler */
  osKernelInitialize();

  /* USER CODE BEGIN RTOS_MUTEX */
  /* add mutexes, ... */
  /* USER CODE END RTOS_MUTEX */

  /* USER CODE BEGIN RTOS_SEMAPHORES */
  /* add semaphores, ... */
  /* USER CODE END RTOS_SEMAPHORES */

  /* Create the timer(s) */
  /* creation of heartbeat_timer */
  heartbeat_timerHandle = osTimerNew(heartbeat_timer_callback, osTimerPeriodic, NULL, &heartbeat_timer_attributes);

  /* USER CODE BEGIN RTOS_TIMERS */
  /* start timers, add new ones, ... */

  osTimerStart(heartbeat_timerHandle, 1000);

  /* USER CODE END RTOS_TIMERS */

  /* USER CODE BEGIN RTOS_QUEUES */
  /* add queues, ... */

  logging_q = xQueueCreate(64, sizeof(LOGGING_Q_ITEM));

  /* USER CODE END RTOS_QUEUES */

  /* Create the thread(s) */
  /* creation of usb_log_task */
  usb_log_taskHandle = osThreadNew(usb_log_task_entry, NULL, &usb_log_task_attributes);

  /* creation of motor_task */
  motor_taskHandle = osThreadNew(motor_task_entry, NULL, &motor_task_attributes);

  /* creation of wifi_task */
  wifi_taskHandle = osThreadNew(wifi_task_entry, NULL, &wifi_task_attributes);

  /* creation of proc_task */
  proc_taskHandle = osThreadNew(proc_task_entry, NULL, &proc_task_attributes);

  /* USER CODE BEGIN RTOS_THREADS */
  /* add threads, ... */
  /* USER CODE END RTOS_THREADS */

  /* USER CODE BEGIN RTOS_EVENTS */
  /* add events, ... */
  /* USER CODE END RTOS_EVENTS */

  /* Start scheduler */
  osKernelStart();

  /* We should never get here as control is now taken by the scheduler */
  /* Infinite loop */
  /* USER CODE BEGIN WHILE */
  while (1)
  {
    /* USER CODE END WHILE */

    /* USER CODE BEGIN 3 */
  }
  /* USER CODE END 3 */
}

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
/* USER CODE BEGIN 4 */

void HAL_ADC_ConvHalfCpltCallback(ADC_HandleTypeDef* hadc) {
	// Indicator that higher priority task has woken while we are in ISR
	BaseType_t xHigherPriorityTaskWoken = pdFALSE;

	adc_buf_state = BUF_HALF_FULL;

	// Waking up task
	vTaskNotifyGiveFromISR(proc_taskHandle, &xHigherPriorityTaskWoken);
	// Run the scheduler upon exit of ISR
	portYIELD_FROM_ISR( xHigherPriorityTaskWoken );
}

void HAL_ADC_ConvCpltCallback(ADC_HandleTypeDef* hadc) {
	// Indicator that higher priority task has woken while we are in ISR
	BaseType_t xHigherPriorityTaskWoken = pdFALSE;

	adc_buf_state = BUF_FULL;

	// Waking up task
	vTaskNotifyGiveFromISR(proc_taskHandle, &xHigherPriorityTaskWoken);
	// Run the scheduler upon exit of ISR
	portYIELD_FROM_ISR( xHigherPriorityTaskWoken );
}

void HAL_I2C_MemRxCpltCallback(I2C_HandleTypeDef* hi2c)
{
	// Indicator that higher priority task has woken while we are in ISR
	BaseType_t xHigherPriorityTaskWoken = pdFALSE;

	if (hi2c == MPU6050.hi2c)
	{
		static uint32_t imu_index = 0;
		static uint8_t imu_buf_id = 0;

		MPU6050_convert_from_raw();

		imu_buf[imu_buf_id].accel_x[imu_index] = MPU6050.accel_x;
		imu_buf[imu_buf_id].accel_y[imu_index] = MPU6050.accel_y;
		imu_buf[imu_buf_id].accel_z[imu_index] = MPU6050.accel_z;

		imu_buf[imu_buf_id].gyro_x[imu_index] = MPU6050.gyro_x;
		imu_buf[imu_buf_id].gyro_y[imu_index] = MPU6050.gyro_y;
		imu_buf[imu_buf_id].gyro_z[imu_index] = MPU6050.gyro_z;

		imu_index++;
		if (imu_index == IMU_BUF_LEN)
		{
			if (imu_buf_id == 0)
			{
				imu_buf_state = BUF_HALF_FULL;
				imu_index = 0;
				imu_buf_id = 1;
			}
			else
			{
				imu_buf_state = BUF_FULL;
				imu_index = 0;
				imu_buf_id = 0;
			}

			vTaskNotifyGiveFromISR(proc_taskHandle, &xHigherPriorityTaskWoken);
		}
	}

	// Run the scheduler upon exit of ISR
	portYIELD_FROM_ISR( xHigherPriorityTaskWoken );
}

void compute_fft_psd(arm_rfft_fast_instance_f32* inst, float* buf_in, float* buf_out, uint32_t L, float fs)
{
	arm_rfft_fast_f32(inst, buf_in, buf_out, 0);
	arm_cmplx_mag_f32(buf_out+2, buf_out+2, L/2-1);

	float nyquist_freq_sample = buf_out[1];
	for (int i=2; i<=L/2; i++)
		buf_out[i-1] = (2.0f*buf_out[i]*buf_out[i]/(L*fs));

	buf_out[0] = (buf_out[0]*buf_out[0]/(L*fs));
	buf_out[L/2] = (nyquist_freq_sample*nyquist_freq_sample/(L*fs));
}




/* USER CODE END 4 */

/* USER CODE BEGIN Header_usb_log_task_entry */
/**
  * @brief  Function implementing the usb_log_task thread.
  * @param  argument: Not used
  * @retval None
  */
/* USER CODE END Header_usb_log_task_entry */
void usb_log_task_entry(void *argument)
{
  /* init code for USB_DEVICE */
  MX_USB_DEVICE_Init();
  /* USER CODE BEGIN 5 */

  MPU6050_init(&hi2c2, &hdma_i2c2_rx);

  LOGGING_Q_ITEM current;
  static char id, signal = 0;

  /* Infinite loop */
  for(;;)
  {
	  if( xQueueReceive( logging_q, &current, portMAX_DELAY) == pdPASS )
	  {
		  signal = usb_rx_buffer[0];

		  if (signal == 'r')
		  {
			  switch (current.id)
			  {
			  case LOG_MIC:
				  id = 'm';
				  break;
			  case LOG_CUR:
				  id = 'c';
				  break;
			  case LOG_IMU:
				  id = 'i';
				  break;
			  case LOG_MIC_FFT:
				  id = 'M';
				  break;
			  case LOG_CUR_FFT:
				  id = 'C';
				  break;
			  case LOG_ACC_X_FFT:
				  id = '1';
				  break;
			  case LOG_ACC_Y_FFT:
				  id = '2';
				  break;
			  case LOG_ACC_Z_FFT:
				  id = '3';
				  break;
			  case LOG_GYR_X_FFT:
				  id = '4';
				  break;
			  case LOG_GYR_Y_FFT:
				  id = '5';
				  break;
			  case LOG_GYR_Z_FFT:
				  id = '6';
				  break;
			  }

			  while (CDC_Transmit_FS((uint8_t*)&id, 1) != USBD_OK)
				  osDelay(1);

			  while (CDC_Transmit_FS(current.buffer, current.size) != USBD_OK)
				  osDelay(1);

			  }

	  }
  }
  /* USER CODE END 5 */
}

/* USER CODE BEGIN Header_motor_task_entry */
/**
* @brief Function implementing the motor_task thread.
* @param argument: Not used
* @retval None
*/
/* USER CODE END Header_motor_task_entry */
void motor_task_entry(void *argument)
{
  /* USER CODE BEGIN motor_task_entry */

  /* Infinite loop */
	osDelay(3000);

	// Enabling the motor driver
	HAL_GPIO_WritePin(MD_NEN_GPIO_Port, MD_NEN_Pin, GPIO_PIN_RESET);
	osDelay(100);



  /* Infinite loop */
  for(;;)
  {
	 uint8_t dir;
	 dir = rand()%2;

	 // Setting a direction
	 if (dir == 0x00)
		 HAL_GPIO_WritePin(MD_DIR_GPIO_Port, MD_DIR_Pin, GPIO_PIN_RESET);
	 else
		 HAL_GPIO_WritePin(MD_DIR_GPIO_Port, MD_DIR_Pin, GPIO_PIN_SET);
	 osDelay(1);

	 int degrees;
	 degrees = rand()%200;

	 for (int i=0; i<degrees*16; i++)
	 {
	 	 HAL_GPIO_WritePin(MD_STEP_GPIO_Port, MD_STEP_Pin, GPIO_PIN_SET);
	     vTaskDelay((TickType_t)pdMS_TO_TICKS(1));
		 HAL_GPIO_WritePin(MD_STEP_GPIO_Port, MD_STEP_Pin, GPIO_PIN_RESET);
	     vTaskDelay((TickType_t)pdMS_TO_TICKS(1));
	 }


	  // Checking the diagnostic pin of the motor driver
	  if (HAL_GPIO_ReadPin(MD_DIAG_GPIO_Port, MD_DIAG_Pin) == GPIO_PIN_SET)
		  HAL_GPIO_WritePin(LED_R_GPIO_Port, LED_R_Pin, GPIO_PIN_RESET);
	  else
		  HAL_GPIO_WritePin(LED_R_GPIO_Port, LED_R_Pin, GPIO_PIN_SET);

	  osDelay(3000);
  }
  /* USER CODE END motor_task_entry */
}

/* USER CODE BEGIN Header_wifi_task_entry */
/**
* @brief Function implementing the wifi_task thread.
* @param argument: Not used
* @retval None
*/
/* USER CODE END Header_wifi_task_entry */
void wifi_task_entry(void *argument)
{
  /* USER CODE BEGIN wifi_task_entry */
	AT_init(&huart3, &hdma_usart3_rx, wifi_taskHandle);

	TS_establish_connection("Alysandratos 2.4GHz", "a1b2c3d4e5");

	float buf[4] = {0};

  /* Infinite loop */
  for(;;)
  {
	  TMP102_read_temperature();
	  buf[0] = TMP102.current_temperature;

	  BME280_read_data();
	  buf[1] = BME280.press;
	  buf[2] = BME280.hum;
	  buf[3] = BME280.temp;

	  TS_send_data("13R16VK6AKMJNERT", buf, 4);
	  osDelay(15000);
  }
  /* USER CODE END wifi_task_entry */
}

/* USER CODE BEGIN Header_proc_task_entry */
/**
* @brief Function implementing the proc_task thread.
* @param argument: Not used
* @retval None
*/
/* USER CODE END Header_proc_task_entry */
void proc_task_entry(void *argument)
{
  /* USER CODE BEGIN proc_task_entry */
	uint32_t L = MIC_BUF_LEN/2;
	arm_rfft_fast_instance_f32 adc_rfft_inst, imu_rfft_inst;

	arm_rfft_512_fast_init_f32(&adc_rfft_inst);
	arm_rfft_64_fast_init_f32(&imu_rfft_inst);


  /* Infinite loop */
  for(;;)
  {

	ulTaskNotifyTake(pdTRUE, portMAX_DELAY);

	if (adc_buf_state == BUF_HALF_FULL)
	{
		// Deinterleaving ADC data
		for (int i=0; i<MIC_BUF_LEN/2; i++)
		{
			mic_buf[i] = adc_raw_buf[2*i] * (2.5f / 4096);
			cur_buf[i] = adc_raw_buf[2*i+1] * (2.5f / 4096);
		}


		// Logging unprocessed
		log_via_USB(mic_buf, (MIC_BUF_LEN/2)*sizeof(float), LOG_MIC);
		log_via_USB(cur_buf, (CUR_BUF_LEN/2)*sizeof(float), LOG_CUR);

		// FFT
		memcpy(fft_mic_in_buf, mic_buf, L*sizeof(float));
		compute_fft_psd(&adc_rfft_inst, fft_mic_in_buf, mic_fft_buf, L, FSAMPLING);
		log_via_USB(mic_fft_buf, (L/2+1)*sizeof(float), LOG_MIC_FFT);


		memcpy(fft_cur_in_buf, cur_buf, L*sizeof(float));
		compute_fft_psd(&adc_rfft_inst, fft_cur_in_buf, cur_fft_buf, L, FSAMPLING);
		log_via_USB(cur_fft_buf, (L/2+1)*sizeof(float), LOG_CUR_FFT);


		adc_buf_state = BUF_EMPTY;
	}

	else if (adc_buf_state == BUF_FULL)
	{
		// Deinterleaving ADC data
		for (int i=MIC_BUF_LEN/2; i<MIC_BUF_LEN; i++)
		{
			mic_buf[i] = adc_raw_buf[2*i] * (2.5f / 4096);
			cur_buf[i] = adc_raw_buf[2*i+1] * (2.5f / 4096);
		}


		// Logging unprocessed
		log_via_USB(mic_buf + MIC_BUF_LEN/2, (MIC_BUF_LEN/2)*sizeof(float), LOG_MIC);
		log_via_USB(cur_buf + CUR_BUF_LEN/2, (CUR_BUF_LEN/2)*sizeof(float), LOG_CUR);

		// FFT
		memcpy(fft_mic_in_buf, mic_buf + MIC_BUF_LEN/2, L*sizeof(float));
		compute_fft_psd(&adc_rfft_inst, fft_mic_in_buf, mic_fft_buf, L, FSAMPLING);
		log_via_USB(mic_fft_buf, (L/2+1)*sizeof(float), LOG_MIC_FFT);


		memcpy(fft_cur_in_buf, cur_buf + CUR_BUF_LEN/2, L*sizeof(float));
		compute_fft_psd(&adc_rfft_inst, fft_cur_in_buf, cur_fft_buf, L, FSAMPLING);
		log_via_USB(cur_fft_buf, (L/2+1)*sizeof(float), LOG_CUR_FFT);

		adc_buf_state = BUF_EMPTY;
	}

	if (imu_buf_state == BUF_HALF_FULL)
	{

		log_via_USB(imu_buf[0].accel_x, sizeof(IMU_BUF), LOG_IMU);


		memcpy(fft_in_imu.accel_x, imu_buf[0].accel_x, sizeof(IMU_BUF));

		compute_fft_psd(&imu_rfft_inst, fft_in_imu.accel_x, imu_fft_buf.accel_x, IMU_BUF_LEN, FSAMPLING);
		log_via_USB(imu_fft_buf.accel_x, (IMU_BUF_LEN/2+1)*sizeof(float), LOG_ACC_X_FFT);

		compute_fft_psd(&imu_rfft_inst, fft_in_imu.accel_y, imu_fft_buf.accel_y, IMU_BUF_LEN, FSAMPLING);
		log_via_USB(imu_fft_buf.accel_y, (IMU_BUF_LEN/2+1)*sizeof(float), LOG_ACC_Y_FFT);

		compute_fft_psd(&imu_rfft_inst, fft_in_imu.accel_z, imu_fft_buf.accel_z, IMU_BUF_LEN, FSAMPLING);
		log_via_USB(imu_fft_buf.accel_z, (IMU_BUF_LEN/2+1)*sizeof(float), LOG_ACC_Z_FFT);

		compute_fft_psd(&imu_rfft_inst, fft_in_imu.gyro_x, imu_fft_buf.gyro_x, IMU_BUF_LEN, FSAMPLING);
		log_via_USB(imu_fft_buf.gyro_x, (IMU_BUF_LEN/2+1)*sizeof(float), LOG_GYR_X_FFT);

		compute_fft_psd(&imu_rfft_inst, fft_in_imu.gyro_y, imu_fft_buf.gyro_y, IMU_BUF_LEN, FSAMPLING);
		log_via_USB(imu_fft_buf.gyro_y, (IMU_BUF_LEN/2+1)*sizeof(float), LOG_GYR_Y_FFT);

		compute_fft_psd(&imu_rfft_inst, fft_in_imu.gyro_z, imu_fft_buf.gyro_z, IMU_BUF_LEN, FSAMPLING);
		log_via_USB(imu_fft_buf.gyro_z, (IMU_BUF_LEN/2+1)*sizeof(float), LOG_GYR_Z_FFT);


		imu_buf_state = BUF_EMPTY;
	}

	else if (imu_buf_state == BUF_FULL)
	{

		log_via_USB(imu_buf[1].accel_x, sizeof(IMU_BUF), LOG_IMU);


		memcpy(fft_in_imu.accel_x, imu_buf[1].accel_x, sizeof(IMU_BUF));

		compute_fft_psd(&imu_rfft_inst, fft_in_imu.accel_x, imu_fft_buf.accel_x, IMU_BUF_LEN, FSAMPLING);
		log_via_USB(imu_fft_buf.accel_x, (IMU_BUF_LEN/2+1)*sizeof(float), LOG_ACC_X_FFT);

		compute_fft_psd(&imu_rfft_inst, fft_in_imu.accel_y, imu_fft_buf.accel_y, IMU_BUF_LEN, FSAMPLING);
		log_via_USB(imu_fft_buf.accel_y, (IMU_BUF_LEN/2+1)*sizeof(float), LOG_ACC_Y_FFT);

		compute_fft_psd(&imu_rfft_inst, fft_in_imu.accel_z, imu_fft_buf.accel_z, IMU_BUF_LEN, FSAMPLING);
		log_via_USB(imu_fft_buf.accel_z, (IMU_BUF_LEN/2+1)*sizeof(float), LOG_ACC_Z_FFT);

		compute_fft_psd(&imu_rfft_inst, fft_in_imu.gyro_x, imu_fft_buf.gyro_x, IMU_BUF_LEN, FSAMPLING);
		log_via_USB(imu_fft_buf.gyro_x, (IMU_BUF_LEN/2+1)*sizeof(float), LOG_GYR_X_FFT);

		compute_fft_psd(&imu_rfft_inst, fft_in_imu.gyro_y, imu_fft_buf.gyro_y, IMU_BUF_LEN, FSAMPLING);
		log_via_USB(imu_fft_buf.gyro_y, (IMU_BUF_LEN/2+1)*sizeof(float), LOG_GYR_Y_FFT);

		compute_fft_psd(&imu_rfft_inst, fft_in_imu.gyro_z, imu_fft_buf.gyro_z, IMU_BUF_LEN, FSAMPLING);
		log_via_USB(imu_fft_buf.gyro_z, (IMU_BUF_LEN/2+1)*sizeof(float), LOG_GYR_Z_FFT);


		imu_buf_state = BUF_EMPTY;
	}


		/*
	process();
	log_processed();
	*/

  }
  /* USER CODE END proc_task_entry */
}

/* heartbeat_timer_callback function */
void heartbeat_timer_callback(void *argument)
{
  /* USER CODE BEGIN heartbeat_timer_callback */

	HAL_GPIO_TogglePin(LED_B_GPIO_Port, LED_B_Pin);

  /* USER CODE END heartbeat_timer_callback */
}

/**
  * @brief  Period elapsed callback in non blocking mode
  * @note   This function is called  when TIM8 interrupt took place, inside
  * HAL_TIM_IRQHandler(). It makes a direct call to HAL_IncTick() to increment
  * a global variable "uwTick" used as application time base.
  * @param  htim : TIM handle
  * @retval None
  */
void HAL_TIM_PeriodElapsedCallback(TIM_HandleTypeDef *htim)
{
  if (htim->Instance == TIM8) {
    HAL_IncTick();
  }
}

/**
  * @brief  This function is executed in case of error occurrence.
  * @retval None
  */
void Error_Handler(void)
{
  /* USER CODE BEGIN Error_Handler_Debug */
  /* User can add his own implementation to report the HAL error return state */
  __disable_irq();
  while (1)
  {
	  HAL_GPIO_TogglePin(LED_R_GPIO_Port, LED_R_Pin);
	  HAL_Delay(100);
  }
  /* USER CODE END Error_Handler_Debug */
}

#ifdef  USE_FULL_ASSERT
/**
  * @brief  Reports the name of the source file and the source line number
  *         where the assert_param error has occurred.
  * @param  file: pointer to the source file name
  * @param  line: assert_param error line source number
  * @retval None
  */
void assert_failed(uint8_t *file, uint32_t line)
{
  /* USER CODE BEGIN 6 */
  /* User can add his own implementation to report the file name and line number,
     ex: printf("Wrong parameters value: file %s on line %d\r\n", file, line) */
  /* USER CODE END 6 */
}
#endif /* USE_FULL_ASSERT */

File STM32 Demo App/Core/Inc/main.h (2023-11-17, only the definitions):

#define CUR_SENS_Pin GPIO_PIN_1
#define CUR_SENS_GPIO_Port GPIOA
#define MIC_SENS_Pin GPIO_PIN_3
#define MIC_SENS_GPIO_Port GPIOA
#define MIC_TH_Pin GPIO_PIN_4
#define MIC_TH_GPIO_Port GPIOA
#define LED_R_Pin GPIO_PIN_8
#define LED_R_GPIO_Port GPIOE
#define LED_G_Pin GPIO_PIN_10
#define LED_G_GPIO_Port GPIOE
#define LED_B_Pin GPIO_PIN_12
#define LED_B_GPIO_Port GPIOE
#define ESP_EN_Pin GPIO_PIN_13
#define ESP_EN_GPIO_Port GPIOE
#define ESP_GPIO1_Pin GPIO_PIN_14
#define ESP_GPIO1_GPIO_Port GPIOE
#define ESP_GPIO0_Pin GPIO_PIN_15
#define ESP_GPIO0_GPIO_Port GPIOE
#define MD_DIAG_Pin GPIO_PIN_10
#define MD_DIAG_GPIO_Port GPIOD
#define MD_INDEX_Pin GPIO_PIN_11
#define MD_INDEX_GPIO_Port GPIOD
#define MD_DIR_Pin GPIO_PIN_15
#define MD_DIR_GPIO_Port GPIOD
#define MD_STEP_Pin GPIO_PIN_2
#define MD_STEP_GPIO_Port GPIOG
#define MD_MS2_Pin GPIO_PIN_4
#define MD_MS2_GPIO_Port GPIOG
#define MD_MS1_Pin GPIO_PIN_5
#define MD_MS1_GPIO_Port GPIOG
#define MD_NEN_Pin GPIO_PIN_6
#define MD_NEN_GPIO_Port GPIOG
#define I2C2_AD0_Pin GPIO_PIN_4
#define I2C2_AD0_GPIO_Port GPIOB
#define I2C2_INT_Pin GPIO_PIN_5
#define I2C2_INT_GPIO_Port GPIOB
#define I2C2_INT_EXTI_IRQn EXTI9_5_IRQn
#define I2C1_AD0_Pin GPIO_PIN_0
#define I2C1_AD0_GPIO_Port GPIOE
#define I2C1_INT_Pin GPIO_PIN_1
#define I2C1_INT_GPIO_Port GPIOE

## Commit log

2023-11-17 Adding STM32CubeIDE files
2023-11-17 KiCAD Files
    [BOMv3.xls, IO_Connectors.sch, Power.sch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]
2023-11-17 STM32CubeIDE Files
2024-07-01 Added nyquist freq sample for FFT.

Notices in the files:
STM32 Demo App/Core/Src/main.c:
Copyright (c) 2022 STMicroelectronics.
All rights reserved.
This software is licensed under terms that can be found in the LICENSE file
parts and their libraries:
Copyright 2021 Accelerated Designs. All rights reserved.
